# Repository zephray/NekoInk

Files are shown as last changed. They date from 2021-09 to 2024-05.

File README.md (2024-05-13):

NekoInk
=======

**This project has been superseded by [Glider](https://gitlab.com/zephray/glider) and will not be updated further.**

NekoInk is an open-source, programmable, and versatile E-paper display platform. It offers connectivity options to various type of E-paper screens, and flexible programming environment choices.

# Hardware

## Mainboard

The 1st generation of NekoInk has the following specs:

* Processing
    - NXP i.MX6ULL, 900 MHz Cortex-A7 processor
    - 512 MB DDR3L-1066 memory
* Display
    - Support for EPD screens from 6" to 13.3"
    - Up to 32 greyscale levels / 32768 colors (depends on screen)
    - 40 pin connector for ED103TC1/ES103TC2/GDEW101C01
    - 6 and 12 pin connector for capacitive touch screen (shared signal)
    - 30 pin connector for LVDS LCDs
* Connectivity
    - MicroSD slot for storage
    - 1x USB Micro-B for USB Device and charging
    - 1x USB Micro-AB for USB Host
    - 1x USB Micro-B for USB Serial terminal
    - 1x DVP port for HDMI input or camera module
    - Integrated WiFi and Bluetooth
* Power
    - AXP209 PMIC with Lithium battery charger and coulomb counter
    - Power consumption T.B.D.

## Screen Adapter

Adapter boards are available in this repo to adapt the following screens:

* 39 pin connector for ED060SC4/ED133UT2
* 34 pin connector for ED060SCF/SCN/SCP/XC3/XC5/XC9/XD4/XD6/XH2/KC1/KD1
* 35 pin connector for ED060XC8/TC1
* 50 pin connector for ES108FC1

It's possible to use a simple FPC extender to support the following screens:

* ED078KC1/KH4/GDEW078M01/078C01

The hardware is designed with KiCAD 7.0.

## Status

The 1st gen mainboard is finished, soldered, and tested and considered stable. However there is no plan for mass-production.

# Software

T.B.D.

## Operating System

Linux T.B.D.

## Waveform

This project uses a human-readable waveform format (iwf, Interchangable Waveform Format) described below. Currently this could be converted into .fw format used by i.MX6/7 EPDC/EPDCv2. Converting from Eink's wbf format is also supported.

### Waveform Format

The waveform consists of one descriptor file in iwf extension (ini format) and various lut data files in csv format.

The descriptor contains the follwoing required fields:

* VERISON: the version of the descriptor
* NAME: (optional) original name for the waveform
* BPP: (optional, default 4) 4 or 5, representing the internal state count used for waveform
* PREFIX: the filename prefix for actual waveform files
* MODES: the total modes supported by the waveform
* TEMPS: the total number of temperature ranges supported by the waveform
* T*x*RANGE: the supported temperature in degC, where x is the temperature ID
* TUPBOUND: (optional) upper bound for temperature range, each range is T*x*RANGE to T*x+1*RANGE (or TUPBOUND in case of the last one)

In v2.0, the following fields are added:

* TABLES: total number of LUTs inside the waveform
* TB*x*FC: the frame count for the table, where x is the table ID

In v1.0, table are directly addressed and stored by its mode and temperature ID (expect things like PREFIX_M1_T2.csv for mode 1 and temperature range 2). In v2.0, tables are indirectly addressed and stored (expect things like PREFIX_TB2.csv for the second table, and one or more mode/temperature combination to use/ reference table 2).

Each mode has its own mode section named \[MODE*x*\], where x is the mode ID, containing the following fields:

* NAME: the name for that mode
* TxFC: the frame count for the temperature in that mode, where x is the temperature ID (v1.0 only)
* T*TABLE: the table used for the temperature in that mode (v2.0 only)

There should be a number of LUTs, saved in the filename of either PREFIX_M*x*_T*y*.csv (v1.0) or PREFIX_TB*x*.csv. Each csv file should contain the a LUT like this: lut\[src\]\[dst\]\[frame\], which means, to transition from src greyscale level to dst greyscale level, at a certain frame in a frame sequence, what voltage should be applied to the screen (0/3: GND / Keep, 1: VNEG / To black, 2: VPOS / To white). Each line contains the frame sequence for one or more source to destination pairs.

For example:

* ```4,7,1,1,1,0,2``` means to transition from greyscale level 4 to greyscale level 7, there should be 5 frames, each applying VNEG VNEG VNEG GND VPOS
* ```0:14:15,2,2,2``` means to transition from any greyscale level from 0 to 14 to greyscale level 15, there should be 3 frames, each applying VPOS VPOS VPOS

These are provided to only illustrate the file format, they are not valid or meaningful Eink driving sequences.

With current design, each mode should have fixed frame count for all associated frame sequences.

### Converting

Tools are provided in utils/ folder.

* To convert from iwf to fw (iMX6/7 EPDC format): ```./mxc_wvfm_asm v1/v2 input.iwf output.fw``` 
* To convert from fw to iwf: ```./mxc_wvfm_dump v1/v2 input.fw output_prefix```
* To convert from wbf to iwf: ```./wbf_wvfm_dump input.wbf output_prefix```

In some cases, the waveform stored on the panel/ controller's flash is compressed. A decompressing tool is also provided that might work.

### Generating

To be implemented.

# License

The design, unless otherwise specified, is released under the CERN Open Source Hardware License version 2 permissive variant, CERN-OHL-P. A copy of the license is provided in the source repository. Additionally, user guide of the license is provided on ohwr.org.

The waveform converting tool is licensed under GNU GPLv2+ due to use of Linux kernel source code and other people's valuable prior work. See each tools' source code for the complete copyright.

The image viewer tool is licensed under MIT. stb library used in the image viewer is public domain.

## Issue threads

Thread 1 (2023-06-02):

ES108FC1

vdp, 2023-06-02:
May I ask on which reference is the pinout used for the ES108FC1 adapter based?

I see that there is for example GDSP signal on pin 43, which is not there in [the datasheet I've found](https://github.com/vroland/epdiy/files/10342125/ES108FC1_Ver0.1.pdf). I'm having trouble driving this screen- it just behaves strangely... For example it only updates at some random instant, then nothing happens, then it may or may not update some time later and so on... Having something left floating which shouldn't be would explain this erratic behaviour, I think. The above preliminary spec is the only 'official' document I've been able to find. This panel is used in Lenovo Yoga Book C930, but the only way to get a schematic seem to be through shady sites which ask to pay them. I would have considered it, but I'm not sure the doc they offer contains relevant info in the first place.

Thanks for your time!

zephray, 2023-06-12:
Hi sorry forgot to reply last week.

It's mainly based on the datasheet you found. However I encountered the same issue as you did, the screen just doesn't work. From looking at the screen flex cable it's obvious these pins are certainly not NC. Basically from trial and error I noticed that connecting GDSP to pin 43 allowed it to work. This is later confirmed by looking at the schematics of C930 (one of my friend eventually decided to pull the trigger and purchased the schematics on one of those shady sites).

vdp, 2023-06-13:
Thank you very much! This is __very__ helpful, because this screen is really driving me crazy. I see that there is a jumper for SDCE0 on pin 36- is it also required for the screen to work properly?

I will try to modify my adapter to see if I can make it work. Other than these 1 or 2 changes, is there something else that I should watch for? For example I have a 10K pull-up R on the test pin 31, just as in your schematic. But I've noticed that sporadically all the lines are activated/charged at the same time, which is basically what pulsing the XON low does, as far as I can see from some driver chip datasheets I found online, so I wonder if a stronger(i.e. lower R value) pull-up may be needed... Also is there anything peculiar about the signal timing for example, that is different from how the other screens are typically driven?

vdp, 2023-06-13:
Thanks a lot! This info is really valuable. Hopefully I will be able to make it work now. (closing the ticket)

Closed 2023-06-13.

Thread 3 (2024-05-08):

v2 MXC Assembly not supported

stephendpmurphy, 2024-05-08:
Hello, I'm attempting to run a conversion from a .WBF to a .FW that the v2 EPDC driver can handle. The conversion from .wbf to .iwf appears to run correctly but it looks like the MXC assembly bin is intentionally asserting that the version of the input file must be for the MXC v1 driver. Is this correct? I'm guessing the assembly piece just isn't finished for the v2 EPDC driver file format?

zephray, 2024-05-09:
The issue is actually that I wrote the WBF decoder much later than the FW decoder/ assembler. So by the time I wrote the WBF decoder I found the initial IWF format I defined is inadequate, so I created a IWF v2 format (likely no one other than me is using the IWF V1 format anyway). But then I never got around to update the FW decoder/ assembler to properly support IWF v2. Thanks for the reminder and I will do that soon. Though if you are trying to use WBF on NXP devices, I would also recommend just reach out to NXP FAEs, they have their proprietary tool for doing so.

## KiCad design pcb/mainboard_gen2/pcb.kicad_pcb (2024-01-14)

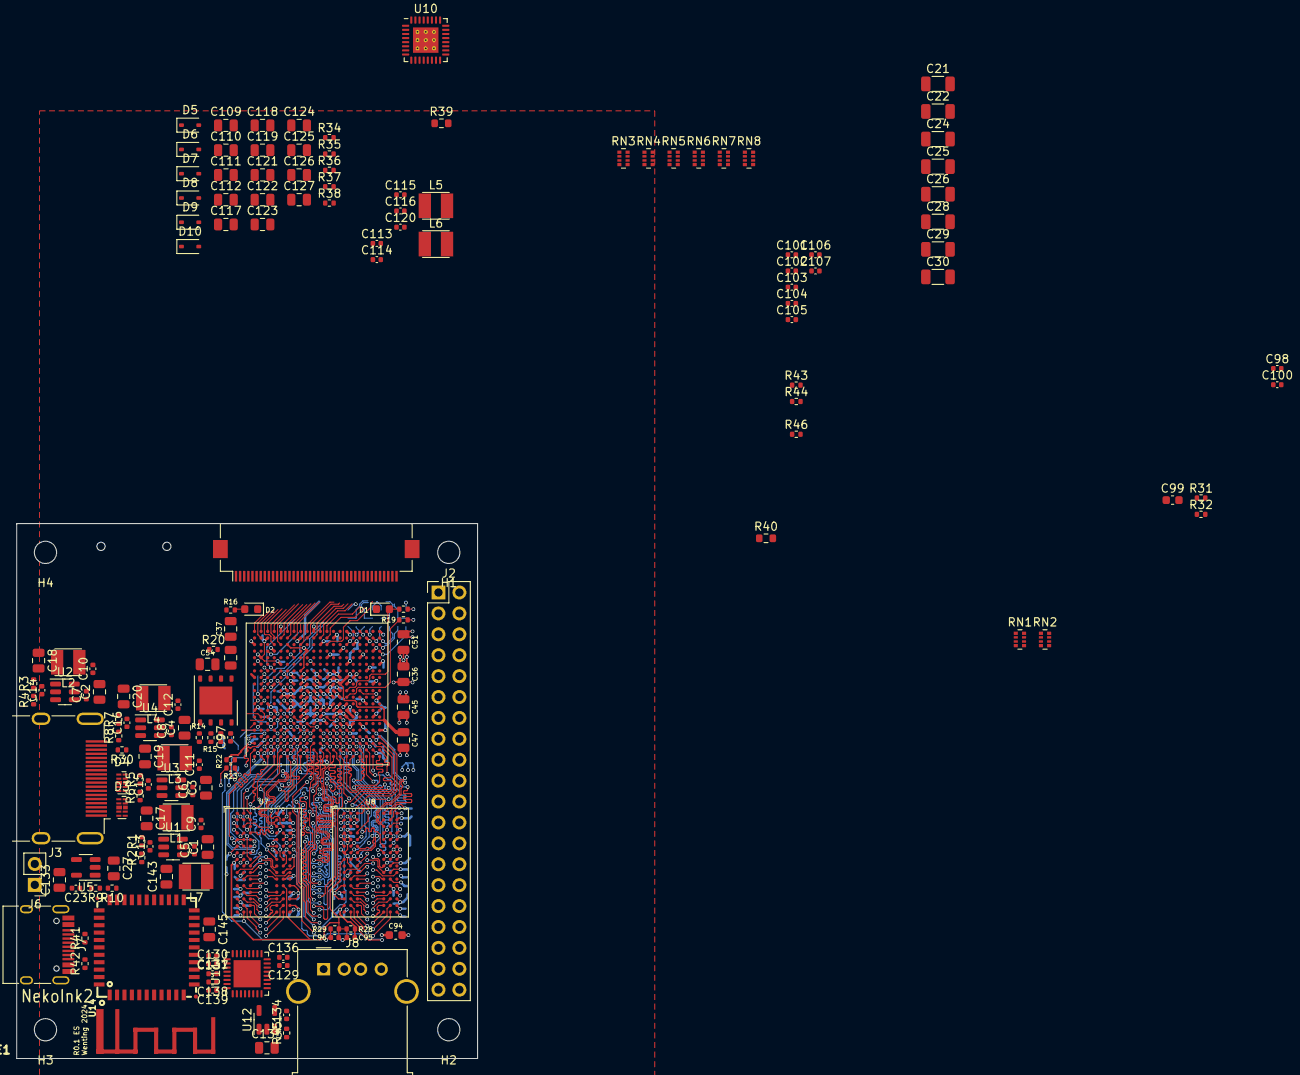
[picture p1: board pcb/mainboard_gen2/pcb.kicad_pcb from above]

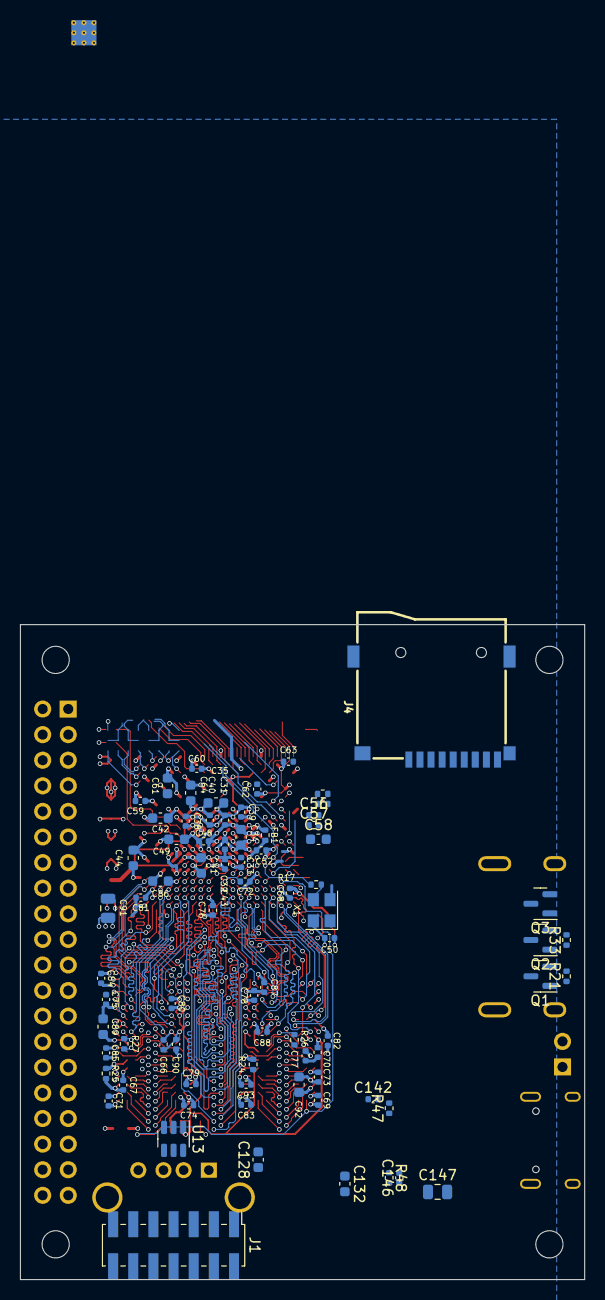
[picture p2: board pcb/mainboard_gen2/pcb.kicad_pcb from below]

Board: 6 copper layers, 56.0 x 65.0 mm, 245 parts (77 on the bottom side), 245 nets.

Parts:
AE1: Antenna_Shield; bt_antenna_1ant_2gnd_mirror
C1, C2, C3, C4, C17, C18, C19, C20, C27, C119, C125, C133, C135, C143, C145, C147: 10uF; C_0805_2012Metric
C5, C6, C7, C8, C9, C10, C11, C12, C23, C67, C70, C95, C96, C100, C113, C114, C115, C129, C130, C131, C134, C136, C137, C138, C139, C142, C146: 100nF; C_0402_1005Metric
C13, C14, C15, C16: 47pF; C_0402_1005Metric
C21, C22, C24, C25, C26, C28, C29, C30: 47uF/10V; C_1206_3216Metric
C31, C32, C33, C38, C39, C40, C43, C48, C50, C52, C56, C57, C59, C60, C62, C63, C68, C72, C76, C81, C97: 470nF; C_0402_1005Metric
C34, C35, C41, C42, C44, C49, C58, C61, C64, C86, C94, C128, C132: 4.7uF; C_0603_1608Metric
C36, C37, C45, C46, C47, C51: 100uF; C_0805_2012Metric
C54, C91: 47uF; C_0805_2012Metric
C66, C69, C71, C73, C74, C75, C77, C78, C79, C80, C82, C83, C84, C85, C87, C88, C90, C93, C101, C102, C103, C104, C105, C106, C107: 220nF; C_0402_1005Metric
C89, C92, C99: 22uF; C_0603_1608Metric
C98: 18pF; C_0402_1005Metric
C109, C110, C111, C112: 1uF/25V; C_0805_2012Metric
C116: 1uF; C_0402_1005Metric
C117, C118, C121, C122, C123, C124, C126, C127: 4.7uF/25V; C_0805_2012Metric
C120: 2.2nF; C_0402_1005Metric
D1, D2: LED; LED_0603_1608Metric
D3, D4: RCLAMP0524P; Diodes_UDFN-10_1.0x2.5mm_P0.5mm
D5, D6, D7, D8, D9, D10: B0530WS; D_SOD-323
FB1: 120R; R_0402_1005Metric
H1, H2, H3, H4: MountingHole; MountingHole_2.7mm_M2.5
J1: JTAG; PinHeader_2x07_P2.00mm_Vertical_SMD
J2: GPIO; PinHeader_2x20_P2.54mm_Vertical
J3: HDMI_A; HDMI_A_Molex_208658-1001_Horizontal
J4: MICRO_SD(TFC-WPAPR-08); TFC-WPAPR-08
J5: 0.5mm; Hirose_FH12-40S-0.5SH_1x40-1MP_P0.50mm_Horizontal_Reversed
J6: Conn_01x02; PinHeader_1x02_P2.54mm_Vertical
J7: USB_C_Receptacle_USB2.0; USB_C_Receptacle_HRO_TYPE-C-31-M-12
J8: USB_A; USB_A_Molex_67643_Horizontal
L1, L2, L3, L4, L5, L6, L7: 4.7uH; L_1212
Q1, Q2, Q3: BSS138; SOT-23
R1: 91K/1%; R_0402_1005Metric
R2, R3, R5: 20K/1%; R_0402_1005Metric
R4: 10K/1%; R_0402_1005Metric
R6, R7: 16K/1%; R_0402_1005Metric
R8, R36: 27K/1%; R_0402_1005Metric
R9, R19: 4.7K; R_0402_1005Metric
R10: 16K; R_0402_1005Metric
R11, R12, R13, R14, R15, R31: 20K; R_0402_1005Metric
R16, R18, R30, R46: 1K; R_0402_1005Metric
R17, R32, R43, R47, R48: 22R; R_0402_1005Metric
R20, R21, R33, R41, R42, R45: 10K; R_0402_1005Metric
R22, R23: 80R; R_0402_1005Metric
R24, R25: 240R 1%; R_0402_1005Metric
R26, R27: 100R; R_0402_1005Metric
R28, R29: 1.5K/0.5%; R_0402_1005Metric
R34: 562K/1%; R_0402_1005Metric
R35: 806K/1%; R_0402_1005Metric
R37: 49.9K/1%; R_0402_1005Metric
R38: 10R; R_0402_1005Metric
R39: 0.5R; R_0603_1608Metric
R40: 22R; R_0603_1608Metric
R44: 12K/1%; R_0402_1005Metric
RN1, RN2: 51; R_Array_Convex_4x0402
RN3, RN4, RN5, RN6, RN7, RN8: 33; R_Array_Convex_4x0402
U1, U2, U3, U4: SY8120; TSOT-23-6
U5, U12: MT9700; SOT-23-5
U6: XC7Z010-CLG400; Xilinx_CLG400
U7, U8: MT41K256M16HA; BGA-96_9.0x13.0mm_Layout2x3x16_P0.8mm
U9: W25Q128JVP; WSON-8-1EP_6x5mm_P1.27mm_EP3.4x4mm
U10: MAX17135; QFN-32-1EP_5x5mm_P0.5mm_EP3.1x3.1mm_ThermalVias
U11: USB3300; QFN-32-1EP_5x5mm_P0.5mm_EP3.3x3.3mm
U13: USBLC6-2SC6; SOT-23-6
U14: AP6330(BCM4330); RL-SM02BD(RTL8723BS)
X1: 33.33MHz; Oscillator_SMD_Abracon_ASE-4Pin_3.2x2.5mm

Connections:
+1V0: C16.2, C20.2, C31.1, C33.1, C35.1, C37.1, C38.1, C39.1, C40.1, C41.1, C42.1, C46.1, C47.1, L4.2, R7.2, U6.G7 (VCCPINT[6]), U6.G11 (VCCBRAM[2]), U6.G13 (VCCINT[9]), U6.H10 (VCCBRAM[2]), U6.H12 (VCCINT[9]), U6.J7 (VCCPINT[6]), U6.J13 (VCCINT[9]), U6.K12 (VCCINT[9]), U6.L7 (VCCPINT[6]), U6.L13 (VCCINT[9]), U6.M12 (VCCINT[9]), U6.N7 (VCCPINT[6]), U6.N13 (VCCINT[9]), U6.P8 (VCCPINT[6]), U6.P12 (VCCINT[9]), U6.R7 (VCCPINT[6]), U6.R13 (VCCINT[9])
+1V8: C14.2, C18.2, C32.1, C34.1, C36.1, C48.1, C49.1, C51.1, C59.1, C60.1, C61.1, FB1.2, L2.2, R3.2, U6.F8 (VCCPAUX[5]), U6.F11 (VCCBATT_0), U6.G9 (VCCPAUX[5]), U6.H8 (VCCPAUX[5]), U6.J9 (VCCADC_0), U6.J11 (VCCAUX[6]), U6.K8 (VCCPAUX[5]), U6.L11 (VCCAUX[6]), U6.M8 (VCCPAUX[5]), U6.N9 (VCCAUX[6]), U6.N11 (VCCAUX[6]), U6.N19 (VCCO_34[6]), U6.P10 (VCCAUX[6]), U6.R9 (VCCAUX[6]), U6.R15 (VCCO_34[6]), U6.T18 (VCCO_34[6]), U6.V14 (VCCO_34[6]), U6.W17 (VCCO_34[6]), U6.Y20 (VCCO_34[6])
+1V35: C15.2, C19.2, C66.1, C68.1, C69.1, C71.1, C72.1, C73.1, C74.1, C75.1, C76.1, C77.1, C78.1, C79.1, C80.1, C81.1, C82.1, C83.1, C84.1, C85.1, C86.1, C87.1, C88.1, C89.1, C90.1, C91.1, C92.1, C93.1, C94.1, C95.1, L3.2, R5.2, R22.1, R28.1, U6.A3 (VCCO_DDR_502[10]), U6.D2 (VCCO_DDR_502[10]), U6.E5 (VCCO_DDR_502[10]), U6.G1 (VCCO_DDR_502[10]), U6.H4 (VCCO_DDR_502[10]), U6.L3 (VCCO_DDR_502[10]), U6.P2 (VCCO_DDR_502[10]), U6.R5 (VCCO_DDR_502[10]), U6.U1 (VCCO_DDR_502[10]), U6.V4 (VCCO_DDR_502[10]), U7.A1 (VDDQ), U7.A8 (VDDQ), U7.B2 (VDD), U7.C1 (VDDQ), U7.C9 (VDDQ), U7.D2 (VDDQ), U7.D9 (VDD), U7.E9 (VDDQ), U7.F1 (VDDQ), U7.G7 (VDD), U7.H2 (VDDQ), U7.H9 (VDDQ), U7.K2 (VDD), U7.K8 (VDD), U7.N1 (VDD), U7.N9 (VDD), U7.R1 (VDD), U7.R9 (VDD), U8.A1 (VDDQ), U8.A8 (VDDQ), U8.B2 (VDD), U8.C1 (VDDQ), U8.C9 (VDDQ), U8.D2 (VDDQ), U8.D9 (VDD), U8.E9 (VDDQ), U8.F1 (VDDQ), U8.G7 (VDD), U8.H2 (VDDQ), U8.H9 (VDDQ), U8.K2 (VDD), U8.K8 (VDD), U8.N1 (VDD), U8.N9 (VDD), U8.R1 (VDD), U8.R9 (VDD)
+3V3: C13.2, C17.2, C43.2, C44.2, C45.2, C50.2, C56.1, C57.1, C58.1, C62.1, C63.1, C64.1, C97.2, C99.1, C100.1, C105.1, C136.1, C137.1, C138.1, C139.1, C142.1, C145.1, C146.1, C147.1, J1.2, J2.1, J2.17, J4.4 (VDD), J5.5, J5.11, L1.2, Q1.1 (G), Q2.1 (G), Q3.1 (G), R1.2, R11.1, R14.1, R18.1, R19.1, R20.1, R21.1, R31.1, R33.1, RN1.1 (R1.1), RN1.2 (R2.1), RN1.3 (R3.1), RN1.4 (R4.1), RN2.1 (R1.1), RN2.2 (R2.1), RN2.3 (R3.1), RN2.4 (R4.1), U6.A13 (VCCO_MIO1_501[4]), U6.B6 (VCCO_MIO0_500[2]), U6.B16 (VCCO_MIO1_501[4]), U6.C19 (VCCO_35[6]), U6.D7 (VCCO_MIO0_500[2]), U6.D12 (VCCO_MIO1_501[4]), U6.E15 (VCCO_MIO1_501[4]), U6.F18 (VCCO_35[6]), U6.H14 (VCCO_35[6]), U6.J17 (VCCO_35[6]), U6.K6 (VCCO_0), U6.K20 (VCCO_35[6]), U6.M6 (CFGBVS_0), U6.M16 (VCCO_35[6]), U6.N6 (RSVDVCC3), U6.R6 (RSVDVCC2), U6.T6 (RSVDVCC1), U6.T8 (VCCO_13[4]), U6.U11 (VCCO_13[4]), U6.W7 (VCCO_13[4]), U6.Y10 (VCCO_13[4]), U9.8 (VCC), U10.11 (VDD), U11.6 (VDD3.3), U11.16 (VDD3.3), U11.25 (VDD3.3), U11.30 (VDD3.3), U11.31 (REG_EN), U14.6 (BT_WAKE), U14.9 (VBAT), U14.22 (VDD_IO), X1.1 (EN), X1.4 (Vdd)
+5V: C1.2, C2.2, C3.2, C4.2, C5.2, C6.2, C7.2, C8.2, C21.2, C22.2, C24.2, C25.2, C26.2, C27.2, C28.2, C29.2, C30.2, J2.2, J2.4, R30.1, U1.4 (~SHDN), U1.5 (IN), U2.4 (~SHDN), U2.5 (IN), U3.4 (~SHDN), U3.5 (IN), U4.4 (~SHDN), U4.5 (IN), U5.1 (VOUT)
+DRAM_VREF: C67.1, C70.1, C95.2, C96.1, R28.2, R29.1, U6.H6 (PS_DDR_VREF0_502), U6.P6 (PS_DDR_VREF1_502), U7.H1 (VrefDQ), U7.M8 (VrefCA), U8.H1 (VrefDQ), U8.M8 (VrefCA)
/connector/HPD_5V: J3.19 (HPD), Q3.3 (D), R30.2
/connector/SCL_5V: J3.15 (SCL), Q1.3 (D)
/connector/SDA_5V: J3.16 (SDA), Q2.3 (D)
/cpu/FPGA_INIT_B: R19.2, U6.R10 (INIT_B_0)
/cpu/LED: R16.1, U6.E6 (PS_MIO0_500)
/cpu/PS_CLK: R17.2, U6.E7 (PS_CLK_500)
/cpu/VCCPLL: C52.2, C54.2, FB1.1, U6.G8 (VCCPLL)
/ddr/DRAM_ADDR0: U6.N2 (PS_DDR_A0_502), U7.N3 (A0), U8.N3 (A0)
/ddr/DRAM_ADDR1: U6.K2 (PS_DDR_A1_502), U7.P7 (A1), U8.P7 (A1)
/ddr/DRAM_ADDR2: U6.M3 (PS_DDR_A2_502), U7.P3 (A2), U8.P3 (A2)
/ddr/DRAM_ADDR3: U6.K3 (PS_DDR_A3_502), U7.N2 (A3), U8.N2 (A3)
/ddr/DRAM_ADDR4: U6.M4 (PS_DDR_A4_502), U7.P8 (A4), U8.P8 (A4)
/ddr/DRAM_ADDR5: U6.L1 (PS_DDR_A5_502), U7.P2 (A5), U8.P2 (A5)
/ddr/DRAM_ADDR6: U6.L4 (PS_DDR_A6_502), U7.R8 (A6), U8.R8 (A6)
/ddr/DRAM_ADDR7: U6.K4 (PS_DDR_A7_502), U7.R2 (A7), U8.R2 (A7)
/ddr/DRAM_ADDR8: U6.K1 (PS_DDR_A8_502), U7.T8 (A8), U8.T8 (A8)
/ddr/DRAM_ADDR9: U6.J4 (PS_DDR_A9_502), U7.R3 (A9), U8.R3 (A9)
/ddr/DRAM_ADDR10: U6.F5 (PS_DDR_A10_502), U7.L7 (A10), U8.L7 (A10)
/ddr/DRAM_ADDR11: U6.G4 (PS_DDR_A11_502), U7.R7 (A11), U8.R7 (A11)
/ddr/DRAM_ADDR12: U6.E4 (PS_DDR_A12_502), U7.N7 (A12/~BC), U8.N7 (A12/~BC)
/ddr/DRAM_ADDR13: U6.D4 (PS_DDR_A13_502), U7.T3 (A13), U8.T3 (A13)
/ddr/DRAM_ADDR14: U6.F4 (PS_DDR_A14_502), U7.T7 (A14/NC), U8.T7 (A14/NC)
/ddr/DRAM_BA0: U6.L5 (PS_DDR_BA0_502), U7.M2 (BA0), U8.M2 (BA0)
/ddr/DRAM_BA1: U6.R4 (PS_DDR_BA1_502), U7.N8 (BA1), U8.N8 (BA1)
/ddr/DRAM_BA2: U6.J5 (PS_DDR_BA2_502), U7.M3 (BA2), U8.M3 (BA2)
/ddr/DRAM_CASB: U6.P5 (PS_DDR_CAS_B_502), U7.K3 (~CAS), U8.K3 (~CAS)
/ddr/DRAM_CKE: U6.N3 (PS_DDR_CKE_502), U7.K9 (CKE), U8.K9 (CKE)
/ddr/DRAM_CKN: R26.2, R27.2, U6.M2 (PS_DDR_CKN_502), U7.K7 (~CK), U8.K7 (~CK)
/ddr/DRAM_CKP: R26.1, R27.1, U6.L2 (PS_DDR_CKP_502), U7.J7 (CK), U8.J7 (CK)
/ddr/DRAM_CSB: U6.N1 (PS_DDR_CS_B_502), U7.L2 (~CS), U8.L2 (~CS)
/ddr/DRAM_DATA0: U6.C3 (PS_DDR_DQ0_502), U7.E3 (DQ0)
/ddr/DRAM_DATA1: U6.B3 (PS_DDR_DQ1_502), U7.F7 (DQ1)
/ddr/DRAM_DATA2: U6.A2 (PS_DDR_DQ2_502), U7.F2 (DQ2)
/ddr/DRAM_DATA3: U6.A4 (PS_DDR_DQ3_502), U7.F8 (DQ3)
/ddr/DRAM_DATA4: U6.D3 (PS_DDR_DQ4_502), U7.H3 (DQ4)
/ddr/DRAM_DATA5: U6.D1 (PS_DDR_DQ5_502), U7.H8 (DQ5)
/ddr/DRAM_DATA6: U6.C1 (PS_DDR_DQ6_502), U7.G2 (DQ6)
/ddr/DRAM_DATA7: U6.E1 (PS_DDR_DQ7_502), U7.H7 (DQ7)
/ddr/DRAM_DATA8: U6.E2 (PS_DDR_DQ8_502), U7.D7 (DQ8)
/ddr/DRAM_DATA9: U6.E3 (PS_DDR_DQ9_502), U7.C3 (DQ9)
/ddr/DRAM_DATA10: U6.G3 (PS_DDR_DQ10_502), U7.C8 (DQ10)
/ddr/DRAM_DATA11: U6.H3 (PS_DDR_DQ11_502), U7.C2 (DQ11)
/ddr/DRAM_DATA12: U6.J3 (PS_DDR_DQ12_502), U7.A7 (DQ12)
/ddr/DRAM_DATA13: U6.H2 (PS_DDR_DQ13_502), U7.A2 (DQ13)
/ddr/DRAM_DATA14: U6.H1 (PS_DDR_DQ14_502), U7.B8 (DQ14)
/ddr/DRAM_DATA15: U6.J1 (PS_DDR_DQ15_502), U7.A3 (DQ15)
/ddr/DRAM_DATA16: U6.P1 (PS_DDR_DQ16_502), U8.E3 (DQ0)
/ddr/DRAM_DATA17: U6.P3 (PS_DDR_DQ17_502), U8.F7 (DQ1)
/ddr/DRAM_DATA18: U6.R3 (PS_DDR_DQ18_502), U8.F2 (DQ2)
/ddr/DRAM_DATA19: U6.R1 (PS_DDR_DQ19_502), U8.F8 (DQ3)
/ddr/DRAM_DATA20: U6.T4 (PS_DDR_DQ20_502), U8.H3 (DQ4)
/ddr/DRAM_DATA21: U6.U4 (PS_DDR_DQ21_502), U8.H8 (DQ5)
/ddr/DRAM_DATA22: U6.U2 (PS_DDR_DQ22_502), U8.G2 (DQ6)
/ddr/DRAM_DATA23: U6.U3 (PS_DDR_DQ23_502), U8.H7 (DQ7)
/ddr/DRAM_DATA24: U6.V1 (PS_DDR_DQ24_502), U8.D7 (DQ8)
/ddr/DRAM_DATA25: U6.Y3 (PS_DDR_DQ25_502), U8.C3 (DQ9)
/ddr/DRAM_DATA26: U6.W1 (PS_DDR_DQ26_502), U8.C8 (DQ10)
/ddr/DRAM_DATA27: U6.Y4 (PS_DDR_DQ27_502), U8.C2 (DQ11)
/ddr/DRAM_DATA28: U6.Y2 (PS_DDR_DQ28_502), U8.A7 (DQ12)
/ddr/DRAM_DATA29: U6.W3 (PS_DDR_DQ29_502), U8.A2 (DQ13)
/ddr/DRAM_DATA30: U6.V2 (PS_DDR_DQ30_502), U8.B8 (DQ14)
/ddr/DRAM_DATA31: U6.V3 (PS_DDR_DQ31_502), U8.A3 (DQ15)
/ddr/DRAM_DQM0: U6.A1 (PS_DDR_DM0_502), U7.E7 (LDM)
/ddr/DRAM_DQM1: U6.F1 (PS_DDR_DM1_502), U7.D3 (UDM)
/ddr/DRAM_DQM2: U6.T1 (PS_DDR_DM2_502), U8.E7 (LDM)
/ddr/DRAM_DQM3: U6.Y1 (PS_DDR_DM3_502), U8.D3 (UDM)
/ddr/DRAM_ODT: U6.N5 (PS_DDR_ODT_502), U7.K1 (ODT), U8.K1 (ODT)
/ddr/DRAM_RASB: U6.P4 (PS_DDR_RAS_B_502), U7.J3 (~RAS), U8.J3 (~RAS)
/ddr/DRAM_RST: U6.B4 (PS_DDR_DRST_B_502), U7.T2 (~RESET), U8.T2 (~RESET)
/ddr/DRAM_SDQSN_0: U6.B2 (PS_DDR_DQS_N0_502), U7.G3 (~LDQS)
/ddr/DRAM_SDQSN_1: U6.F2 (PS_DDR_DQS_N1_502), U7.B7 (~UDQS)
/ddr/DRAM_SDQSN_2: U6.T2 (PS_DDR_DQS_N2_502), U8.G3 (~LDQS)
/ddr/DRAM_SDQSN_3: U6.W4 (PS_DDR_DQS_N3_502), U8.B7 (~UDQS)
/ddr/DRAM_SDQSP_0: U6.C2 (PS_DDR_DQS_P0_502), U7.F3 (LDQS)
/ddr/DRAM_SDQSP_1: U6.G2 (PS_DDR_DQS_P1_502), U7.C7 (UDQS)
/ddr/DRAM_SDQSP_2: U6.R2 (PS_DDR_DQS_P2_502), U8.F3 (LDQS)
/ddr/DRAM_SDQSP_3: U6.W5 (PS_DDR_DQS_P3_502), U8.C7 (UDQS)
/ddr/DRAM_WEB: U6.M5 (PS_DDR_WE_B_502), U7.L3 (~WE), U8.L3 (~WE)
/usb/HOST_VBUS: C135.1, J8.1 (VBUS), R46.1, U12.1 (VOUT), U13.5 (VBUS)
/usb/USB_DM: J8.2 (D-), U11.8 (DM), U13.1 (I/O1), U13.6 (I/O1)
/usb/USB_DP: J8.3 (D+), U11.7 (DP), U13.3 (I/O2), U13.4 (I/O2)
BT_SHUTDOWN: U6.F14 (PS_MIO21_501), U14.34 (BT_RST_N)
BT_UART_RXD: U6.B18 (PS_MIO18_501), U14.42 (UART_TXD)
BT_UART_TXD: U6.D10 (PS_MIO19_501), U14.43 (UART_RXD)
DDC_SCL: Q1.2 (S), R21.2, U6.J14 (IO_L20N_T3_AD6N_35)
DDC_SDA: Q2.2 (S), R33.2, U6.N16 (IO_L21N_T3_DQS_AD14N_35)
EPDC_D0: RN4.6 (R3.2), U6.F16 (IO_L6P_T0_35)
EPDC_D1: RN4.7 (R2.2), U6.F17 (IO_L6N_T0_VREF_35)
EPDC_D2: RN4.8 (R1.2), U6.M19 (IO_L7P_T1_AD2P_35)
EPDC_D3: RN5.5 (R4.2), U6.M20 (IO_L7N_T1_AD2N_35)
EPDC_D4: RN5.6 (R3.2), U6.M17 (IO_L8P_T1_AD10P_35)
EPDC_D5: RN5.7 (R2.2), U6.L20 (IO_L9N_T1_DQS_AD3N_35)
EPDC_D6: RN5.8 (R1.2), U6.L19 (IO_L9P_T1_DQS_AD3P_35)
EPDC_D7: RN6.5 (R4.2), U6.J19 (IO_L10N_T1_AD11N_35)
EPDC_D8: RN6.6 (R3.2), U6.K19 (IO_L10P_T1_AD11P_35)
EPDC_D9: RN6.7 (R2.2), U6.B19 (IO_L2P_T0_AD8P_35)
EPDC_D10: RN6.8 (R1.2), U6.B20 (IO_L1N_T0_AD0N_35)
EPDC_D11: RN7.5 (R4.2), U6.A20 (IO_L2N_T0_AD8N_35)
EPDC_D12: RN7.6 (R3.2), U6.E18 (IO_L5P_T0_AD9P_35)
EPDC_D13: RN7.7 (R2.2), U6.D20 (IO_L4N_T0_35)
EPDC_D14: RN7.8 (R1.2), U6.D19 (IO_L4P_T0_35)
EPDC_D15: RN8.5 (R4.2), U6.E17 (IO_L3P_T0_DQS_AD1P_35)
EPDC_GDCLK: RN3.7 (R2.2), U6.J15 (IO_25_35)
EPDC_GDOE: RN3.6 (R3.2), U6.G14 (IO_0_35)
EPDC_GDSP: RN3.8 (R1.2), U6.C20 (IO_L1P_T0_AD0P_35)
EPDC_SDCE0: RN8.6 (R3.2), U6.E19 (IO_L5N_T0_AD9N_35)
EPDC_SDCLK: RN4.5 (R4.2), U6.D18 (IO_L3N_T0_DQS_AD1N_35)
EPDC_SDLE: RN8.7 (R2.2), U6.L17 (IO_L11N_T1_SRCC_35)
EPDC_SDOE: RN8.8 (R1.2), U6.M18 (IO_L8N_T1_AD10N_35)
FPGA_DONE: D1.2 (A), Q3.2 (S), R18.2, U6.L15 (IO_L22N_T3_AD7N_35), U6.R11 (DONE_0)
FPGA_TCK: J1.6, U6.F9 (TCK_0)
FPGA_TDI: J1.10, U6.G6 (TDI_0)
FPGA_TDO: J1.8, U6.F6 (TDO_0)
FPGA_TMS: J1.4, U6.J6 (TMS_0)
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

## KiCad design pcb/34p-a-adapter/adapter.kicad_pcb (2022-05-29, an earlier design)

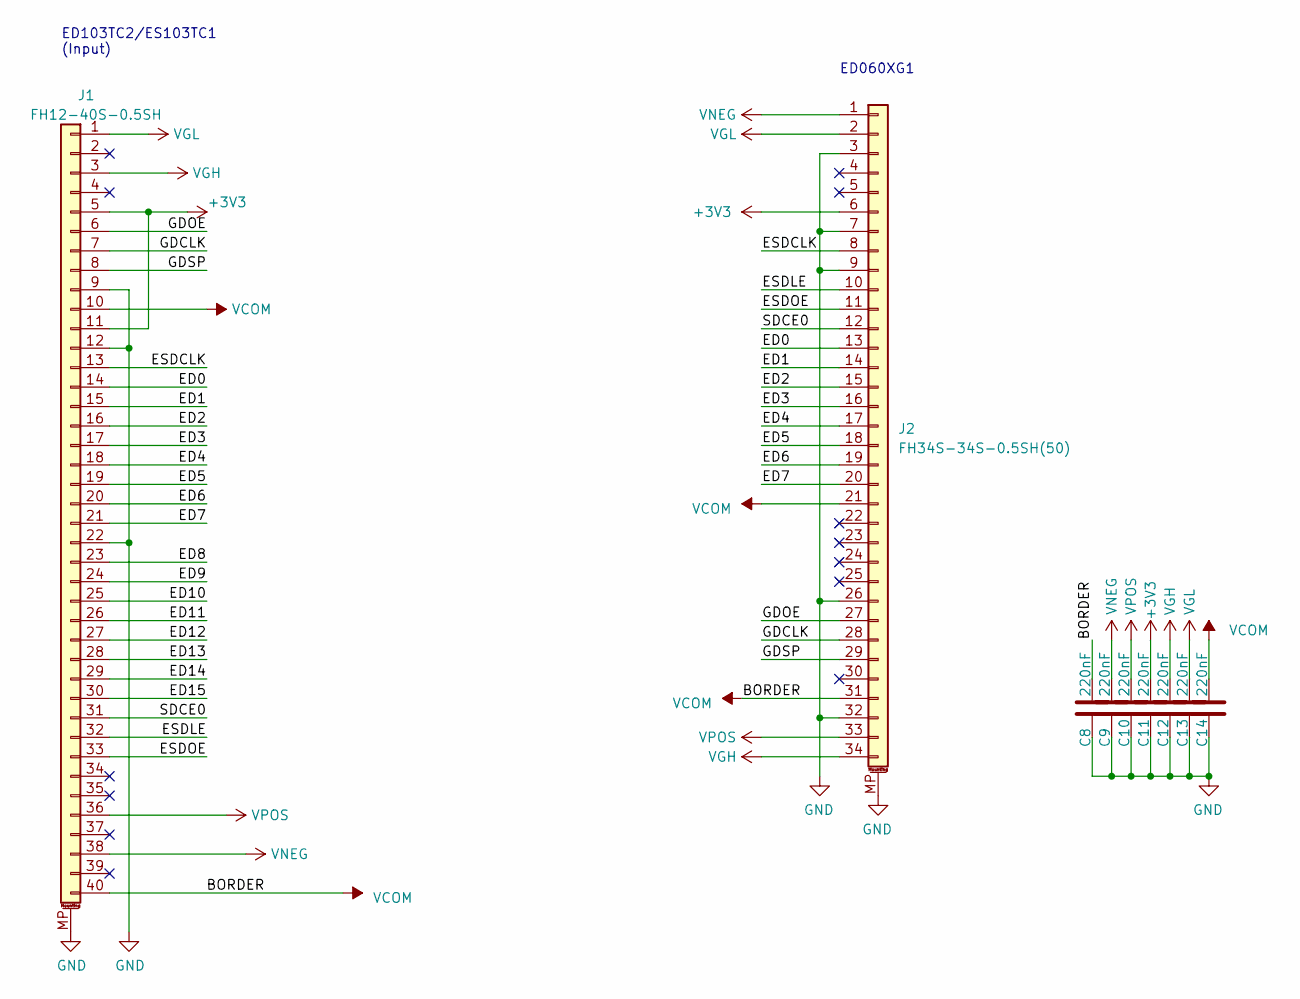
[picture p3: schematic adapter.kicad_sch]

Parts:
C8, C9, C10, C11, C12, C13, C14: 220nF; C_0402_1005Metric; LCSC C880414
J1: FH12-40S-0.5SH; Hirose_FH12-40S-0.5SH_1x40-1MP_P0.50mm_Horizontal_Reversed
J2: FH34S-34S-0.5SH(50); Hirose_FH12-34S-0.5SH_1x34-1MP_P0.50mm_Horizontal

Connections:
+3V3: C11.1, J1.5, J1.11, J2.6
/ED0: J1.14, J2.13
/ED1: J1.15, J2.14
/ED2: J1.16, J2.15
/ED3: J1.17, J2.16
/ED4: J1.18, J2.17
/ED5: J1.19, J2.18
/ED6: J1.20, J2.19
/ED7: J1.21, J2.20
/ED8: J1.23
/ED9: J1.24
/ED10: J1.25
/ED11: J1.26
/ED12: J1.27
/ED13: J1.28
/ED14: J1.29
/ED15: J1.30
/ESDCLK: J1.13, J2.8
/ESDLE: J1.32, J2.10
/ESDOE: J1.33, J2.11
/GDCLK: J1.7, J2.28
/GDOE: J1.6, J2.27
/GDSP: J1.8, J2.29
/SDCE0: J1.31, J2.12
GND: C8.2, C9.2, C10.2, C11.2, C12.2, C13.2, C14.2, J1.9, J1.12, J1.22, J1.MP (MountPin), J2.3, J2.7, J2.9, J2.26, J2.32, J2.MP (MountPin)
VCOM: C8.1, C14.1, J1.10, J1.40, J2.21, J2.31
VGH: C12.1, J1.3, J2.34
VGL: C13.1, J1.1, J2.2
VNEG: C9.1, J1.38, J2.1
VPOS: C10.1, J1.36, J2.33

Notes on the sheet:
ED103TC2/ES103TC1 (Input)
ED060XG1

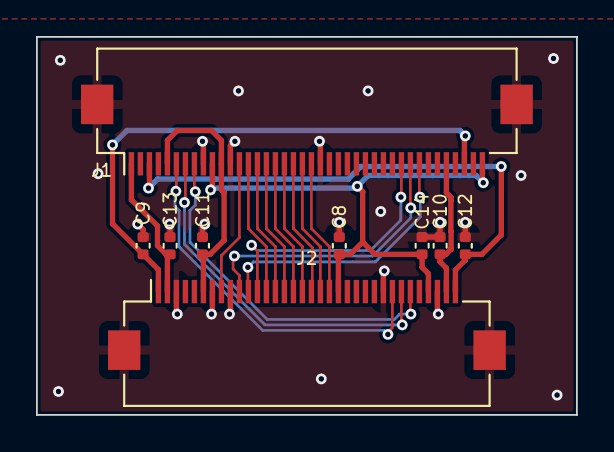
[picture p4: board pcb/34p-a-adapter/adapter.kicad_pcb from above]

Board: 2 copper layers, 30.0 x 21.0 mm, 9 parts (0 on the bottom side), 22 nets.

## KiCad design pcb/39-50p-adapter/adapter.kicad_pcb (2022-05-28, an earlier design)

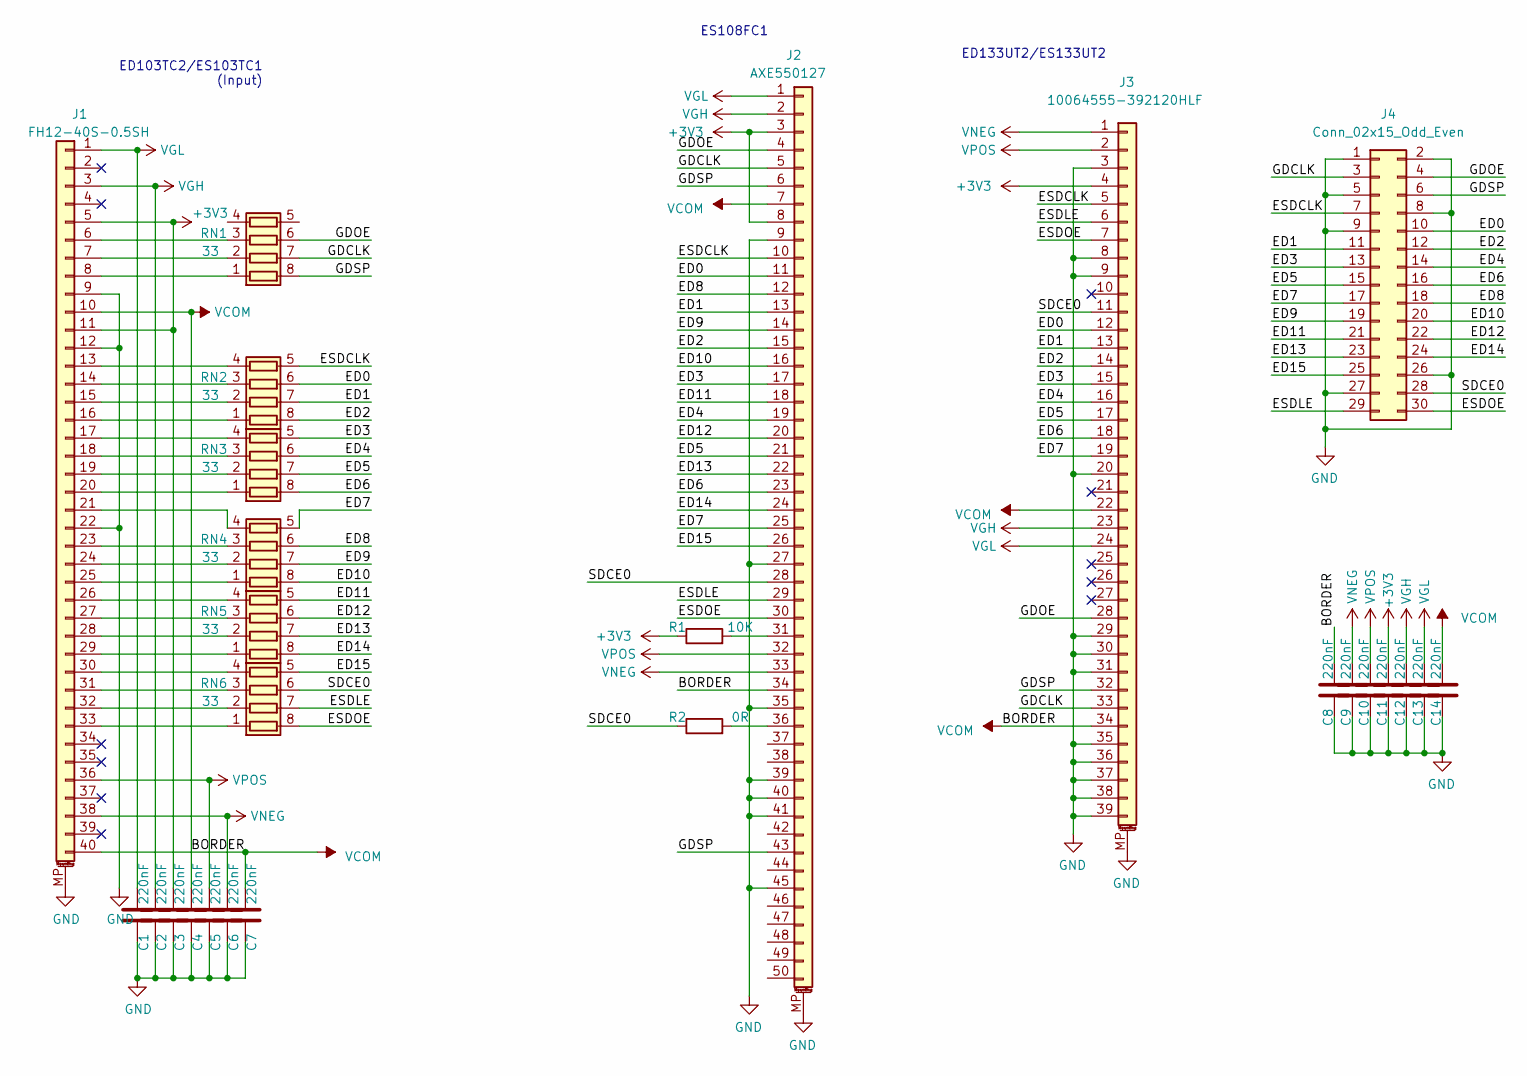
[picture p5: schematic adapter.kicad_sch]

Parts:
C1, C2, C3, C4, C5, C6, C7: 220nF; C_0402_1005Metric
C8, C9, C10, C11, C12, C13, C14: 220nF; C_0402_1005Metric; LCSC C880414
J1: FH12-40S-0.5SH; Hirose_FH12-40S-0.5SH_1x40-1MP_P0.50mm_Horizontal_Reversed
J2: AXE550127
J3: 10064555-392120HLF; FCI_10064555-392120HLF; LCSC 609-10064555-392120HLFCT-ND
J4: Conn_02x15_Odd_Even; PinHeader_2x15_P2.00mm_Vertical
R1: 10K; R_0402_1005Metric; LCSC C105870
R2: 0R; R_0402_1005Metric; LCSC C60485
RN1, RN2, RN3, RN4, RN5, RN6: 33; R_Array_Convex_4x0402

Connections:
/ED0: J2.11, J3.12, J4.10, RN2.6 (R3.2)
/ED1: J2.13, J3.13, J4.11, RN2.7 (R2.2)
/ED2: J2.15, J3.14, J4.12, RN2.8 (R1.2)
/ED3: J2.17, J3.15, J4.13, RN3.5 (R4.2)
/ED4: J2.19, J3.16, J4.14, RN3.6 (R3.2)
/ED5: J2.21, J3.17, J4.15, RN3.7 (R2.2)
/ED6: J2.23, J3.18, J4.16, RN3.8 (R1.2)
/ED7: J2.25, J3.19, J4.17, RN4.5 (R4.2)
/ED8: J2.12, J4.18, RN4.6 (R3.2)
/ED9: J2.14, J4.19, RN4.7 (R2.2)
/ED10: J2.16, J4.20, RN4.8 (R1.2)
/ED11: J2.18, J4.21, RN5.5 (R4.2)
/ED12: J2.20, J4.22, RN5.6 (R3.2)
/ED13: J2.22, J4.23, RN5.7 (R2.2)
/ED14: J2.24, J4.24, RN5.8 (R1.2)
/ED15: J2.26, J4.25, RN6.5 (R4.2)
/ESDCLK: J2.10, J3.5, J4.7, RN2.5 (R4.2)
/ESDLE: J2.29, J3.6, J4.29, RN6.7 (R2.2)
/ESDOE: J2.30, J3.7, J4.30, RN6.8 (R1.2)
/GDCLK: J2.5, J3.33, J4.3, RN1.7 (R2.2)
/GDOE: J2.4, J3.28, J4.4, RN1.6 (R3.2)
/GDSP: J2.6, J2.43, J3.32, J4.6, RN1.8 (R1.2)
/SDCE0: J2.28, J3.11, J4.28, R2.1, RN6.6 (R3.2)
GND: C1.2, C2.2, C3.2, C4.2, C5.2, C6.2, C7.2, C8.2, C9.2, C10.2, C11.2, C12.2, C13.2, C14.2, J1.9, J1.12, J1.22, J1.MP (MountPin), J2.9, J2.27, J2.35, J2.39, J2.40, J2.41, J2.45, J2.MP (MountPin), J3.3, J3.8, J3.9, J3.20, J3.29, J3.30, J3.31, J3.35, J3.36, J3.37, J3.38, J3.39, J3.MP (MountPin), J4.1, J4.2, J4.5, J4.8, J4.9, J4.26, J4.27
unnamed: J1.6, RN1.3 (R3.1)
unnamed: J1.7, RN1.2 (R2.1)
unnamed: J1.8, RN1.1 (R1.1)
unnamed: J1.13, RN2.4 (R4.1)
unnamed: J1.14, RN2.3 (R3.1)
unnamed: J1.15, RN2.2 (R2.1)
unnamed: J1.16, RN2.1 (R1.1)
unnamed: J1.17, RN3.4 (R4.1)
unnamed: J1.18, RN3.3 (R3.1)
unnamed: J1.19, RN3.2 (R2.1)
unnamed: J1.20, RN3.1 (R1.1)
unnamed: J1.21, RN4.4 (R4.1)
unnamed: J1.23, RN4.3 (R3.1)
unnamed: J1.24, RN4.2 (R2.1)
unnamed: J1.25, RN4.1 (R1.1)
unnamed: J1.26, RN5.4 (R4.1)
unnamed: J1.27, RN5.3 (R3.1)
unnamed: J1.28, RN5.2 (R2.1)
unnamed: J1.29, RN5.1 (R1.1)
unnamed: J1.30, RN6.4 (R4.1)
unnamed: J1.31, RN6.3 (R3.1)
unnamed: J1.32, RN6.2 (R2.1)
unnamed: J1.33, RN6.1 (R1.1)
unnamed: J2.31, R1.2
unnamed: J2.36, R2.2
VCOM: C4.1, C7.1, C8.1, C14.1, J1.10, J1.40, J2.7, J2.34, J3.22, J3.34
VGH: C2.1, C12.1, J1.3, J2.2, J3.23
VGL: C1.1, C13.1, J1.1, J2.1, J3.24
VNEG: C6.1, C9.1, J1.38, J2.33, J3.1
VPOS: C5.1, C10.1, J1.36, J2.32, J3.2

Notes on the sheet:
ES108FC1
ED103TC2/ES103TC1 (Input)
ED133UT2/ES133UT2

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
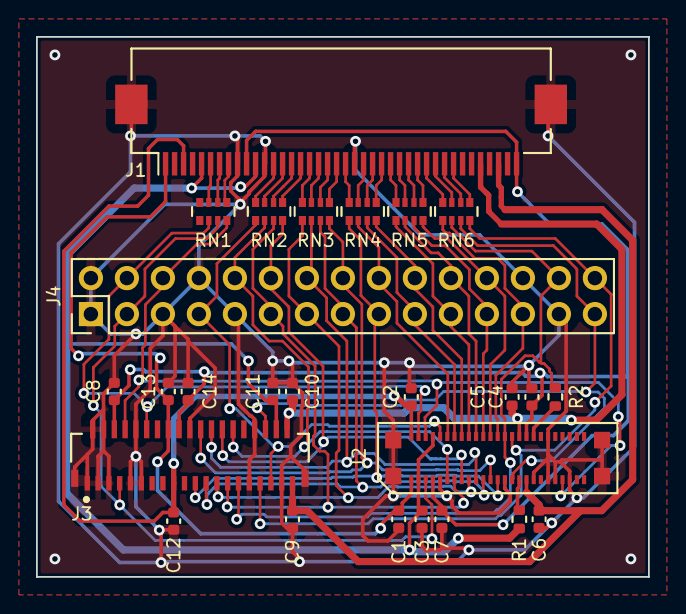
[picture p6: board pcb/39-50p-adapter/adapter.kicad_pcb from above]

Board: 2 copper layers, 34.0 x 30.0 mm, 26 parts (0 on the bottom side), 55 nets.

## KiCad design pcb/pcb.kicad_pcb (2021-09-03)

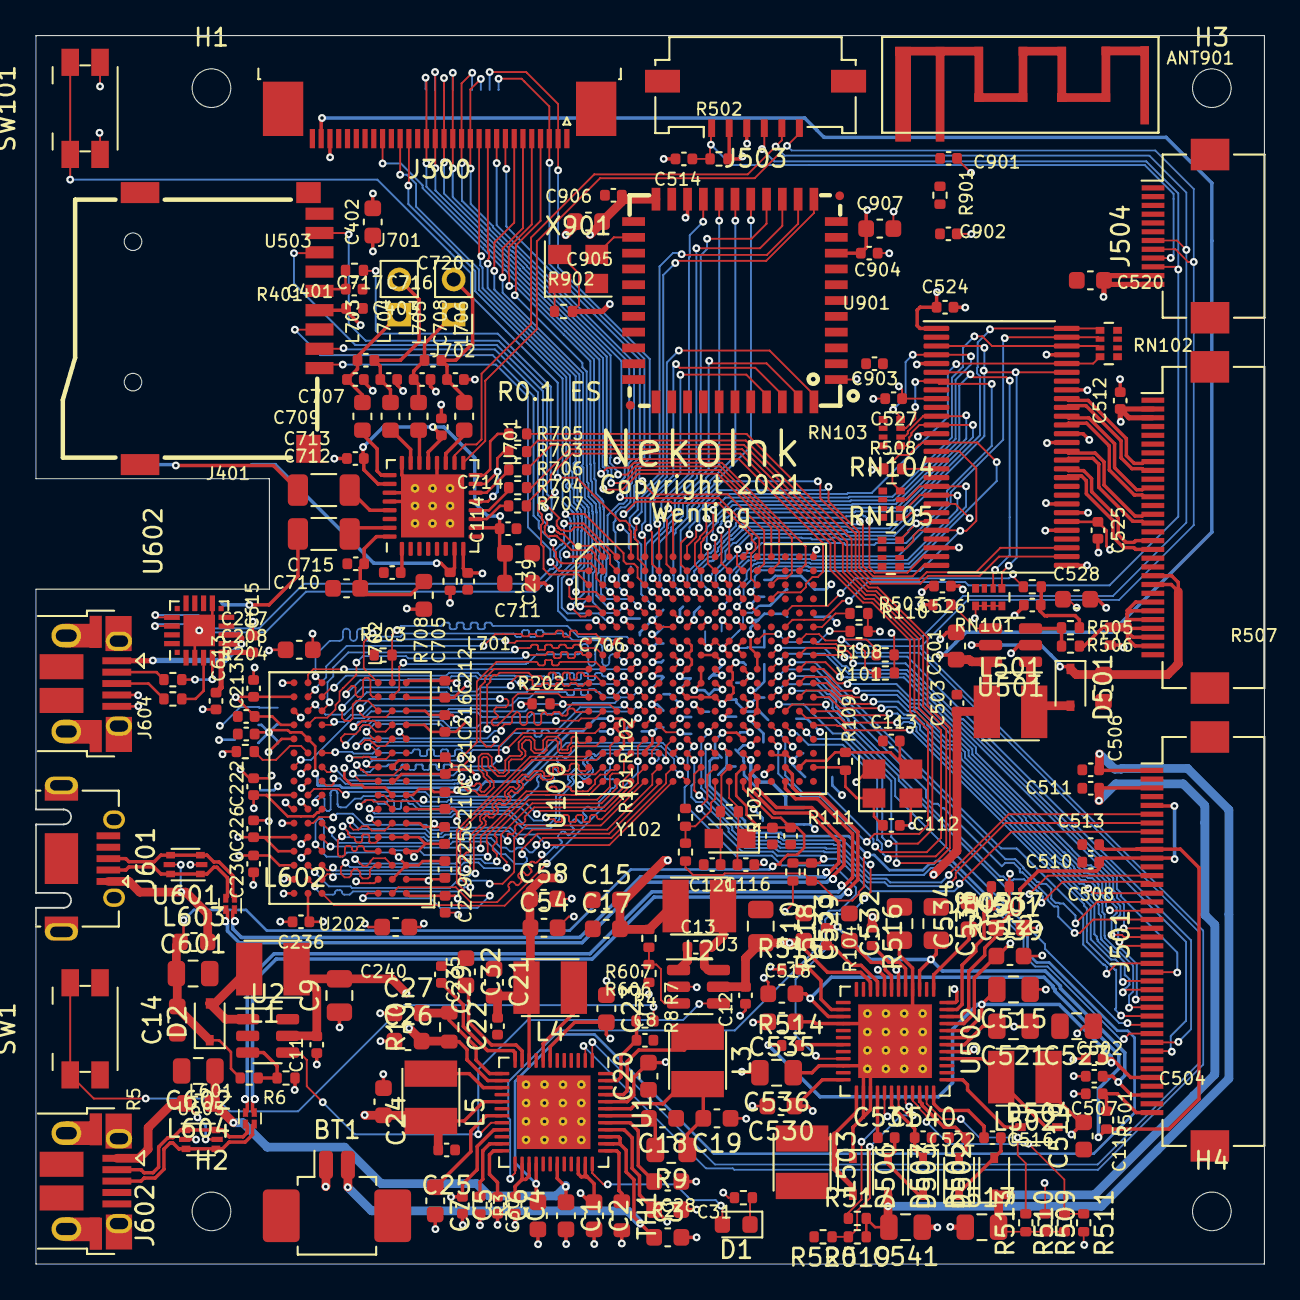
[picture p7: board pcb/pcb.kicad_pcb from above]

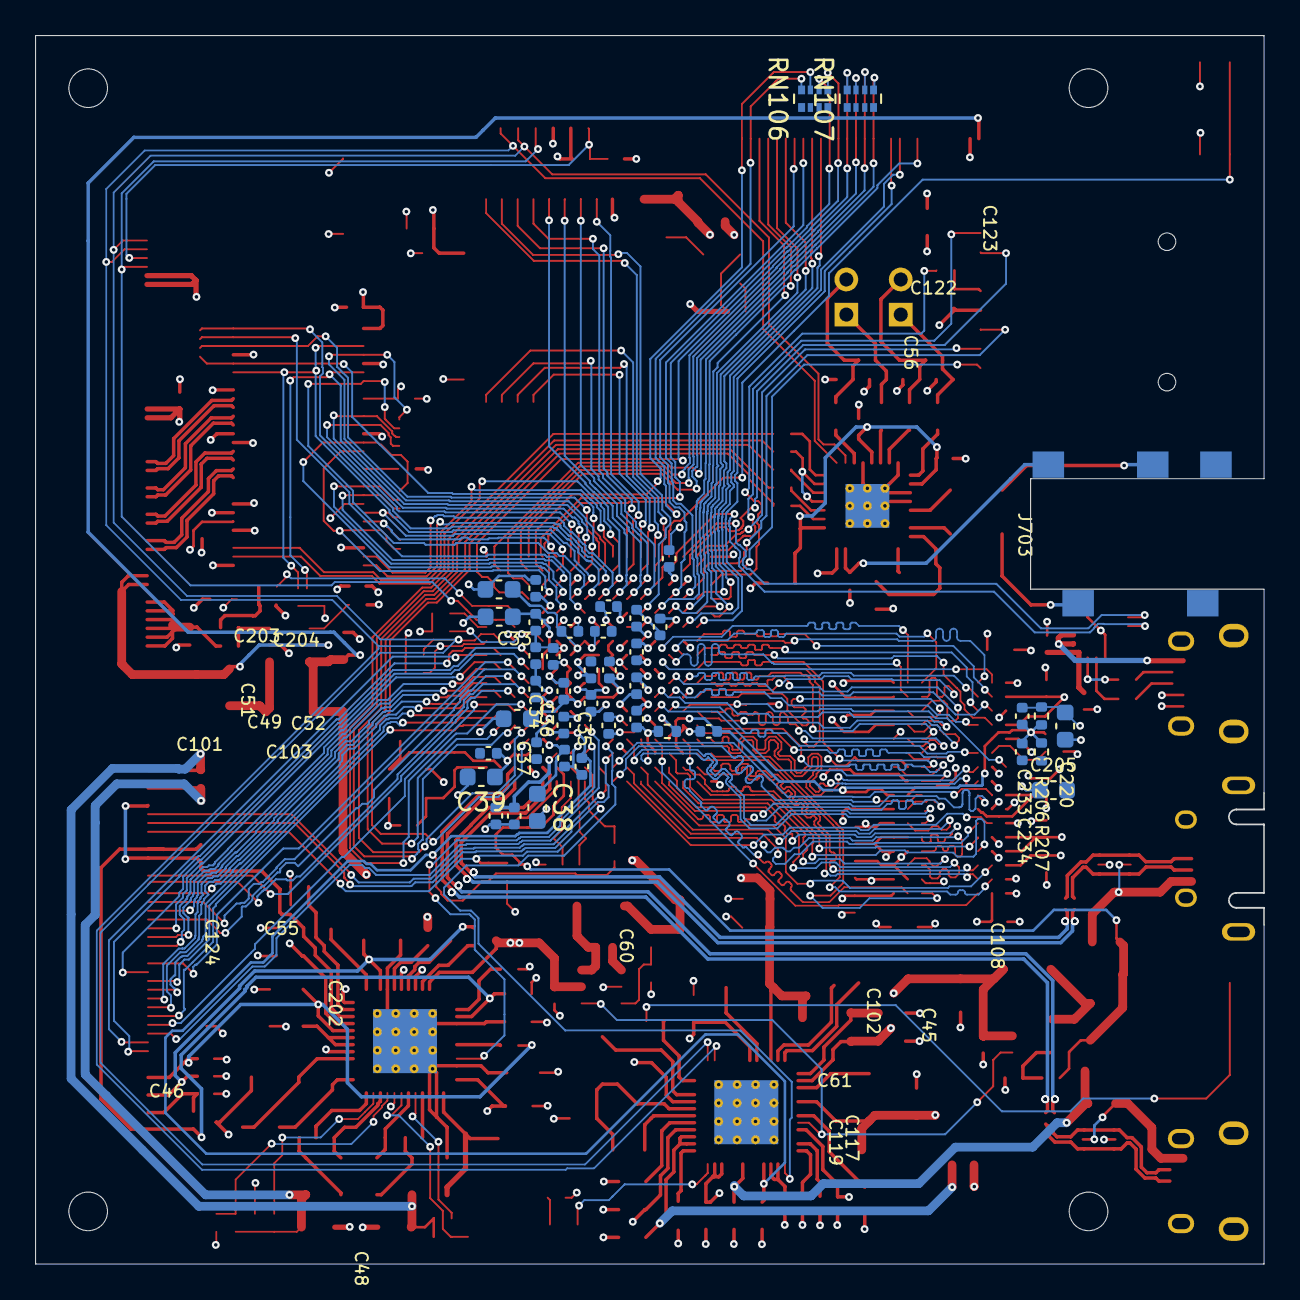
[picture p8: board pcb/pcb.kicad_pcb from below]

Board: 4 copper layers, 70.0 x 70.0 mm, 289 parts (42 on the bottom side), 275 nets.

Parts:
ANT901: PCB_WIFI_ANT; bt_antenna_1ant_2gnd
BT1: Conn_01x02; Molex_PicoBlade_53261-0271_1x02-1MP_P1.25mm_Horizontal
C1, C2, C3, C14, C15, C17, C18, C19, C20, C21, C23, C24, C26, C27, C32, C38, C39, C501, C519, C530, C905, C907: 10uF; C_0603_1608Metric
C4, C6, C119: 2.2uF; C_0402_1005Metric
C5, C34, C35, C36, C37, C45, C46, C48, C49, C51, C52, C55, C56, C101, C102, C103, C108, C114, C115, C117, C122, C123, C124, C201, C202, C203, C204, C207, C208, C210, C212, C213, C216, C217, C221, C222, C225, C226, C229, C230, C235, C236, C502, C504, C505, C507, C508, C510, C511, C513, C514, C524, C525, C526, C527: 220nF; C_0402_1005Metric
C7, C28, C30, C31, C33, C58, C220, C518, C529, C533, C534, C535, C537, C539, C710, C711: 4.7uF; C_0603_1608Metric
C8, C11, C12, C13, C29, C206, C233, C234, C403, C503, C512, C516, C540, C613, C615, C714, C715, C716, C717, C718, C904, C906: 100nF; C_0402_1005Metric
C9, C10, C515, C517, C521, C523, C532, C536, C538, C541: 4.7uF/25V; C_0805_2012Metric
C22, C25: 1nF; C_0402_1005Metric
C54, C60, C61, C205, C239, C240, C402, C528: 22uF; C_0603_1608Metric
C112, C113, C401: 18pF; C_0402_1005Metric
C116, C121: DNP/18pF; C_0402_1005Metric
C506: 1uF/35V; C_0603_1608Metric
C520: 10uF/6.3V; C_0603_1608Metric
C522, C531: 10nF; C_0402_1005Metric
C601, C602: 10uF/25V; C_0805_2012Metric
C705, C706, C707, C708, C709, C719, C720: 470nF; C_0402_1005Metric
C712, C713: 100uF; C_1206_3216Metric
C901, C902: DNP; C_0402_1005Metric
C903: 33pF/50V/5%; C_0402_1005Metric
D1: LED; D_0603_1608Metric
D2, D501, D502, D503, D504, D505, D506, D507: B0530WS; D_SOD-323
H1, H2, H3, H4: MountingHole; MountingHole_2.2mm_M2_DIN965
J300: Conn_01x30_MountingPin; TE_3-1734839-0_1x30-1MP_P0.5mm_Horizontal
J401: MICRO_SD(TFC-WPAPR-08); TFC-WPAPR-08
J501: 0.5mm; Hirose_FH12-40S-0.5SH_1x40-1MP_P0.50mm_Horizontal_Reversed
J502: Conn_01x30_MountingPin; Hirose_FH12-30S-0.5SH_1x30-1MP_P0.50mm_Horizontal_Reversed
J503: 1mm; Molex_200528-0060_1x06-1MP_P1.00mm_Horizontal_Reversed
J504: 0.5mm; Hirose_FH12-12S-0.5SH_1x12-1MP_P0.50mm_Horizontal_Reversed
J601: USB_AB_Micro; USB_Micro-AB_Molex_47590-0001
J602, J604: USB_B_Micro; USB_Micro-B_Amphenol_10103594-0001LF_Horizontal
J701, J702: Conn_01x02; PinHeader_1x02_P2.00mm_Vertical
J703: AudioJack3_SwitchT; PJ-327E
L1, L2, L3, L4, L5, L501: 4.7uH; L_1212
L502, L503: 2.2uH; L_1212
L601, L602: EXC14CE900U; L_CommonModeChoke_Panasonic_EXC14CE
L603, L604, L701, L702: 120R; L_0603_1608Metric
L703, L704, L705, L706: 15uH; L_0603_1608Metric
R2, R4: 1K; R_0402_1005Metric
R3: 200K; R_0402_1005Metric
R5: 200K/1%; R_0402_1005Metric
R6, R8: 27K/1%; R_0402_1005Metric
R7: 121K/1%; R_0402_1005Metric
R9: 0.03R; R_0805_2012Metric
R10: 1R; R_0603_1608Metric
R101, R104, R105, R107, R108, R110, R202, R203, R502, R503, R505, R508, R902: 10K; R_0402_1005Metric
R102, R103: DNP/10K; R_0402_1005Metric
R109: 1M; R_0402_1005Metric
R111: DNP/4.75M; R_0402_1005Metric
R201, R204: 240R 1%; R_0402_1005Metric
R206, R207: 1.5K/0.5%; R_0402_1005Metric
R401: 33; R_0402_1005Metric
R501, R901: 0R; R_0402_1005Metric
R504: 49.9K/1%; R_0402_1005Metric
R506: 3.3K; R_0402_1005Metric
R507: 1.8R; R_0402_1005Metric
R509, R516, R708: 100K; R_0402_1005Metric
R510: 976K/1%; R_0402_1005Metric
R511: 36K/1%; R_0402_1005Metric
R512: 43K; R_0402_1005Metric
R513, R514, R515, R517, R518: NC; R_0402_1005Metric
R519: 1M/1%; R_0402_1005Metric
R520: 52.3K/1%; R_0402_1005Metric
R606, R607: 22; R_0402_1005Metric
R703, R704, R705, R706, R707: 22R; R_0402_1005Metric
RN101, RN102, RN103, RN104, RN105, RN106, RN107: 10K; R_Array_Convex_4x0402
SW1, SW101: EVQPUJ02K; Panasonic_EVQPUJ_EVQPUA
TH1: 10K; R_0603_1608Metric
TH501: 10K; R_0402_1005Metric
U1: AXP209; QFN-48-1EP_6x6mm_P0.4mm_EP4.2x4.2mm_ThermalVias
U2: SY7208; SOT-23-6
U3: SY8120; TSOT-23-6
U100: MCIMX6Y7DVM09AB; BGA-289_17x17_14.0x14.0mm
U202: MT41K256M16HA; BGA-96_9.0x13.0mm_P0.8mm
U501: AP3031; SOT-23-6
U502: TPS65185; QFN-48-1EP_6x6mm_P0.4mm_EP4.2x4.2mm_ThermalVias
U503: DS90C385A/GM8285C; TSSOP-56_6.1x14mm_P0.5mm
U601, U605: USBLC6-2P6; SOT-666
U602: CP2102N-Axx-xQFN20; SiliconLabs_QFN-20-1EP_3x3mm_P0.5mm_EP1.8x1.8mm
U701: WM8960; QFN-32-1EP_5x5mm_P0.5mm_EP3.6x3.6mm_ThermalVias
U901: RTL8723BS; RL-SM02BD(RTL8723BS)
X901: 32.768kHz; Oscillator_SMD_Abracon_ASE-4Pin_3.2x2.5mm
Y101: 24MHz; Oscillator_SMD_Abracon_ASE-4Pin_3.2x2.5mm
Y102: 32.768kHz; Crystal_SMD_TXC_9HT11-2Pin_2.0x1.2mm_HandSoldering

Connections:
+1V5: C21.2, C22.2, C45.1, C48.1, C54.1, C58.1, L4.2, U1.10 (DCDC2), U100.H9 (VDD_SOC_IN), U100.H10 (VDD_SOC_IN), U100.J9 (VDD_SOC_IN), U100.J10 (VDD_SOC_IN), U100.K9 (VDD_SOC_IN), U100.K10 (VDD_SOC_IN)
+1V35: C24.2, C25.2, C201.1, C202.1, C203.1, C204.1, C205.1, C212.1, C213.1, C216.1, C217.1, C220.1, C221.1, C222.1, C225.1, C226.1, C229.1, C230.1, C233.1, C235.1, C236.1, C239.1, C240.1, L5.2, R206.1, U1.17 (DCDC3), U100.G6 (NVCC_DRAM), U100.H6 (NVCC_DRAM), U100.J6 (NVCC_DRAM), U100.K6 (NVCC_DRAM), U100.L6 (NVCC_DRAM), U100.M6 (NVCC_DRAM), U202.A1 (VDDQ), U202.A8 (VDDQ), U202.B2 (VDD), U202.C1 (VDDQ), U202.C9 (VDDQ), U202.D2 (VDDQ), U202.D9 (VDD), U202.E9 (VDDQ), U202.F1 (VDDQ), U202.G7 (VDD), U202.H2 (VDDQ), U202.H9 (VDDQ), U202.K2 (VDD), U202.K8 (VDD), U202.N1 (VDD), U202.N9 (VDD), U202.R1 (VDD), U202.R9 (VDD)
+3.3VA: C32.2, U1.11 (LDO4)
+3V3: C15.2, C17.2, C33.1, C34.1, C101.1, C102.1, C103.1, C108.1, C122.1, C123.1, C124.1, C402.1, C403.1, C512.1, C520.1, C524.1, C525.1, C526.1, C527.1, C528.1, C539.1, C705.1, C904.1, C905.1, C906.1, C907.1, J300.28, J401.4 (VDD), J502.2, J502.3, J503.2, J504.11, J504.12, L2.2, L701.2, L702.2, R7.2, R105.1, R107.1, R108.1, R110.1, R502.1, R508.1, R708.1, R902.1, RN101.5 (R4.2), RN101.6 (R3.2), RN101.7 (R2.2), RN101.8 (R1.2), U100.C4 (NVCC_SD1), U100.E7 (NVCC_NAND), U100.E13 (NVCC_LED), U100.F4 (NVCC_CSI), U100.F13 (NVCC_ENET), U100.H13 (NVCC_UART), U100.J13 (NVCC_GPIO), U100.L13 (VDDA_ADC_3P3), U100.M13 (ADC_VREFH), U100.N13 (VDD_HIGH_IN), U502.45 (VIN3P3), U503.1 (VCC), U503.9 (VCC), U503.26 (VCC), U503.34 (PLL_VCC), U503.44 (LVDS_VCC), U701.8 (DCVDD), U901.9 (VDD33), U901.22 (VDD_IO), X901.4 (Vdd)
+3V3_LCD: C510.1, C537.1, J501.5, J501.11, U502.46 (V3P3)
+5V: C14.2, C114.1, C115.1, C601.1, D2.1 (K), L603.1, R5.2, U100.T12 (USB_OTG1_VBUS), U100.U12 (USB_OTG2_VBUS)
+BATT: BT1.2, C3.1, C18.2, R9.2, U1.38 (BAT), U1.39 (BAT), U1.42 (BATSENSE)
+DRAM_VREF: C206.1, C208.1, C210.1, C233.2, C234.1, R206.2, R207.1, U100.P4 (DRAM_VREF), U202.H1 (VrefDQ), U202.M8 (VrefCA)
+RTC: C30.2, C35.1, R101.2, R103.2, U1.28 (LDO1), U100.P12 (VDD_SNVS_IN)
+VDD_HIGH_CAP: C207.1, U100.N6 (NVCC_DRAM_2P5)
/audio/MICBIAS: C715.1, U701.1 (MICBIAS)
/cpu/BOOTMODE1: R101.1, R102.2, U100.U10 (BOOT_MODE1)
/ddr/DRAM_ADDR0: U100.L5 (DRAM_ADDR0), U202.N3 (A0)
/ddr/DRAM_ADDR1: U100.H2 (DRAM_ADDR1), U202.P7 (A1)
/ddr/DRAM_ADDR2: U100.K1 (DRAM_ADDR2), U202.P3 (A2)
/ddr/DRAM_ADDR3: U100.M2 (DRAM_ADDR3), U202.N2 (A3)
/ddr/DRAM_ADDR4: U100.K4 (DRAM_ADDR4), U202.P8 (A4)
/ddr/DRAM_ADDR5: U100.L1 (DRAM_ADDR5), U202.P2 (A5)
/ddr/DRAM_ADDR6: U100.G2 (DRAM_ADDR6), U202.R8 (A6)
/ddr/DRAM_ADDR7: U100.H4 (DRAM_ADDR7), U202.R2 (A7)
/ddr/DRAM_ADDR8: U100.J4 (DRAM_ADDR8), U202.T8 (A8)
/ddr/DRAM_ADDR9: U100.L2 (DRAM_ADDR9), U202.R3 (A9)
/ddr/DRAM_ADDR10: U100.M4 (DRAM_ADDR10), U202.L7 (A10)
/ddr/DRAM_ADDR11: U100.K3 (DRAM_ADDR11), U202.R7 (A11)
/ddr/DRAM_ADDR12: U100.L4 (DRAM_ADDR12), U202.N7 (A12/~BC)
/ddr/DRAM_ADDR13: U100.H3 (DRAM_ADDR13), U202.T3 (A13)
/ddr/DRAM_ADDR14: U100.G1 (DRAM_ADDR14), U202.T7 (A14/NC)
/ddr/DRAM_BA0: U100.M1 (DRAM_SDBA0), U202.M2 (BA0)
/ddr/DRAM_BA1: U100.H1 (DRAM_SDBA1), U202.N8 (BA1)
/ddr/DRAM_BA2: U100.K2 (DRAM_SDBA2), U202.M3 (BA2)
/ddr/DRAM_CASB: U100.J2 (~DRAM_CAS), U202.K3 (~CAS)
/ddr/DRAM_CKE: R202.2, U100.M3 (DRAM_SDCKE0), U202.K9 (CKE)
/ddr/DRAM_CKN: U100.P2 (DRAM_SDCLK0_N), U202.K7 (~CK)
/ddr/DRAM_CKP: U100.P1 (DRAM_SDCLK0_P), U202.J7 (CK)
/ddr/DRAM_CSB: U100.N2 (~DRAM_CS0), U202.L2 (~CS)
/ddr/DRAM_DATA0: U100.T4 (DRAM_DATA0), U202.E3 (DQ0)
/ddr/DRAM_DATA1: U100.U6 (DRAM_DATA1), U202.F7 (DQ1)
/ddr/DRAM_DATA2: U100.T6 (DRAM_DATA2), U202.F2 (DQ2)
/ddr/DRAM_DATA3: U100.U7 (DRAM_DATA3), U202.F8 (DQ3)
/ddr/DRAM_DATA4: U100.U8 (DRAM_DATA4), U202.H3 (DQ4)
/ddr/DRAM_DATA5: U100.T8 (DRAM_DATA5), U202.H8 (DQ5)
/ddr/DRAM_DATA6: U100.T5 (DRAM_DATA6), U202.G2 (DQ6)
/ddr/DRAM_DATA7: U100.U4 (DRAM_DATA7), U202.H7 (DQ7)
/ddr/DRAM_DATA8: U100.U2 (DRAM_DATA8), U202.D7 (DQ8)
/ddr/DRAM_DATA9: U100.U3 (DRAM_DATA9), U202.C3 (DQ9)
/ddr/DRAM_DATA10: U100.U5 (DRAM_DATA10), U202.C8 (DQ10)
/ddr/DRAM_DATA11: U100.R4 (DRAM_DATA11), U202.C2 (DQ11)
/ddr/DRAM_DATA12: U100.P5 (DRAM_DATA12), U202.A7 (DQ12)
/ddr/DRAM_DATA13: U100.P3 (DRAM_DATA13), U202.A2 (DQ13)
/ddr/DRAM_DATA14: U100.R2 (DRAM_DATA14), U202.B8 (DQ14)
/ddr/DRAM_DATA15: U100.R1 (DRAM_DATA15), U202.A3 (DQ15)
/ddr/DRAM_DQM0: U100.T7 (DRAM_DQM0), U202.D3 (UDM)
/ddr/DRAM_DQM1: U100.T3 (DRAM_DQM1), U202.E7 (LDM)
/ddr/DRAM_ODT: U100.N1 (DRAM_ODT0), U202.K1 (ODT)
/ddr/DRAM_RASB: U100.M5 (~DRAM_RAS), U202.J3 (~RAS)
/ddr/DRAM_RST: R203.2, U100.G4 (DRAM_RESET), U202.T2 (~RESET)
/ddr/DRAM_WEB: U100.J1 (~DRAM_SDWE), U202.L3 (~WE)
/lcd/BORDER: C502.1, J501.40, R501.2
/lcd/EPD_TP_RST: C514.1, J503.1, J504.9, R502.2
/lcd/LEDA: C506.2, D501.1 (K), J502.21, J502.22, U501.5 (OVP)
/lcd/LEDK: J502.24, J502.25, J502.26, J502.27, J502.28, J502.29, R506.1, R507.1
/lcd/LVDS_CKN: J502.17, U503.40 (TxCLKOUT-)
/lcd/LVDS_CKP: J502.18, U503.39 (TxCLKOUT+)
/lcd/LVDS_D0N: J502.8, U503.48 (TxOUT0-)
/lcd/LVDS_D0P: J502.9, U503.47 (TxOUT0+)
/lcd/LVDS_D1N: J502.11, U503.46 (TxOUT1-)
/lcd/LVDS_D1P: J502.12, U503.45 (TxOUT1+)
/lcd/LVDS_D2N: J502.14, U503.42 (TxOUT2-)
/lcd/LVDS_D2P: J502.15, U503.41 (TxOUT2+)
/power/EXTEN: U1.20 (EXTEN), U2.4 (EN), U3.4 (RUN)
/power/NVCC_PLL: C37.1, C38.1, U100.P13 (NVCC_PLL)
/power/TS: TH1.1, U1.37 (TS)
/power/VDD_ARM_CAP: C51.1, C55.1, C60.1, U100.G9 (VDD_ARM_CAP), U100.G10 (VDD_ARM_CAP), U100.G11 (VDD_ARM_CAP), U100.H11 (VDD_ARM_CAP)
/power/VDD_HIGH_CAP: C39.1, C46.1, U100.R14 (VDD_HIGH_CAP), U100.R15 (VDD_HIGH_CAP)
/power/VDD_SNVS_CAP: C36.1, U100.N12 (VDD_SNVS_CAP)
/power/VDD_SOC_CAP: C49.1, C52.1, C56.1, C61.1, U100.G8 (VDD_SOC_CAP), U100.H8 (VDD_SOC_CAP), U100.J8 (VDD_SOC_CAP), U100.J11 (VDD_SOC_CAP), U100.K8 (VDD_SOC_CAP), U100.K11 (VDD_SOC_CAP), U100.L8 (VDD_SOC_CAP), U100.L9 (VDD_SOC_CAP), U100.L10 (VDD_SOC_CAP), U100.L11 (VDD_SOC_CAP)
/power/VINT: C4.1, U1.26 (VINT), U1.27 (LDO1SET)
/usb/DEVICE_DN: J602.2 (D-), L601.4, U605.1 (I/O1), U605.6 (I/O1)
/usb/DEVICE_DP: J602.3 (D+), L601.3, U605.3 (I/O2), U605.4 (I/O2)
/usb/HOST_DN: J601.2 (D-), L602.3, U601.1 (I/O1), U601.6 (I/O1)
/usb/HOST_DP: J601.3 (D+), L602.4, U601.3 (I/O2), U601.4 (I/O2)
CSI_D0: J300.2, RN106.7 (R2.2), U100.B13 (LCD_DATA17)
CSI_D1: J300.3, RN106.8 (R1.2), U100.C13 (LCD_DATA16)
CSI_D2: J300.4, U100.E4 (CSI_DATA0)
CSI_D3: J300.5, U100.E3 (CSI_DATA1)
CSI_D4: J300.6, U100.E2 (CSI_DATA2)
CSI_D5: J300.7, U100.E1 (CSI_DATA3)
CSI_D6: J300.8, U100.D4 (CSI_DATA4)
CSI_D7: J300.9, U100.D3 (CSI_DATA5)
CSI_D8: J300.10, U100.D2 (CSI_DATA6)
CSI_D9: J300.11, U100.D1 (CSI_DATA7)
CSI_D10: J300.12, RN106.6 (R3.2), U100.A13 (LCD_DATA18)
CSI_D11: J300.13, RN106.5 (R4.2), U100.D14 (LCD_DATA19)
CSI_D12: J300.14, RN107.8 (R1.2), U100.C14 (LCD_DATA20)
CSI_D13: J300.15, RN107.7 (R2.2), U100.B14 (LCD_DATA21)
CSI_D14: J300.16, RN107.6 (R3.2), U100.A14 (LCD_DATA22)
CSI_D15: J300.17, RN107.5 (R4.2), U100.B16 (LCD_DATA23)
CSI_HSYNC: J300.20, U100.F3 (CSI_HSYNC)
CSI_PIXCLK: J300.22, U100.E5 (CSI_PIXCLK)
CSI_VSYNC: J300.19, U100.F2 (CSI_VSYNC)
EPDC_D0: J501.14, U100.L14 (GPIO1_IO2)
EPDC_D1: J501.15, U100.L17 (GPIO1_IO3)
EPDC_D2: J501.16, U100.K14 (UART1_TX_DATA)
EPDC_D3: J501.17, U100.K16 (UART1_RX_DATA)
EPDC_D4: J501.18, U100.K15 (~UART1_CTS)
EPDC_D5: J501.19, U100.J14 (~UART1_RTS)
EPDC_D6: J501.20, U100.J17 (UART2_TX_DATA)
EPDC_D7: J501.21, U100.J16 (UART2_RX_DATA)
EPDC_D8: J501.23, U100.J15 (~UART1_CTS)
EPDC_D9: J501.24, U100.H14 (~UART2_RTS)
EPDC_D10: J501.25, U100.M16 (GPIO1_IO4)
EPDC_D11: J501.26, U100.M17 (GPIO1_IO5)
EPDC_D12: J501.27, U100.K17 (GPIO1_IO6)
EPDC_D13: J501.28, U100.L16 (GPIO1_IO7)
EPDC_D14: J501.29, U100.N17 (GPIO1_IO8)
EPDC_D15: J501.30, U100.M15 (GPIO1_IO9)
EPDC_GDCLK: J501.7, U100.R8 (ONOFF)
EPDC_GDOE: J501.6, U100.T9 (SNVS_PMIC_ON_REQ)
EPDC_GDSP: J501.8, R103.1, R104.2, U100.T10 (BOOT_MODE0)
EPDC_SDCE0: J501.31, U100.N10 (SNVS_TAMPER7)
EPDC_SDCLK: J501.13, U100.L15 (GPIO1_IO1)
EPDC_SDLE: J501.32, U100.H17 (UART3_TX_DATA)
EPDC_SDOE: J501.33, U100.H16 (UART3_RX_DATA)
EPD_PWR_EN: U100.R10 (SNVS_TAMPER0), U502.21 (PWRUP)
EPD_TP_INT: J503.4, J504.10, U100.F15 (ENET1_TX_EN)
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

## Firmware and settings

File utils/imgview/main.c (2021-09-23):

//
// NekoInk Image Viewer
// Copyright 2021 Wenting Zhang
//
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
// File : main.c
// Brief: Main entry point of the application
//
#include <stdio.h>
#include <stdlib.h>
#include <stdbool.h>
#include <stdint.h>
#include <time.h>
#include "config.h"
#include "disp.h"

#if defined(BUILD_PC_SIM)
#include <SDL.h>
#endif

#define PROFILE(x) { \
    clock_t t = clock();\
    x;\
    t = clock() - t;\
    printf("%.2f ms\n", (double)t / CLOCKS_PER_SEC * 1000);\
}

void dump_hex(uint8_t *buf, int count) {
    for (int i = 0; i < count / 16; i++) {
        for (int j = 0; j < 16; j++) {
            printf("%02x ", *buf++);
        }
        printf("\n");
    }
}

int main(int argc, char *argv[]) {
    if (argc < 2) {
        fprintf(stderr, "Usage: imgview <path_to_image>\n");
        return 1;
    }

#ifdef ENABLE_COLOR
    Canvas *target = disp_create(DISP_WIDTH, DISP_HEIGHT, PIXFMT_RGB888);
#else
    Canvas *target = disp_create(DISP_WIDTH, DISP_HEIGHT, PIXFMT_Y8);
#endif
    Rect zero_rect = {0};

    disp_init();

    Canvas *image;
    
    printf("Loading image: ");
    PROFILE(image = disp_load_image(argv[1]));

    if (image->pixelFormat != target->pixelFormat) {
        Canvas *image_new = disp_create(image->width, image->height, target->pixelFormat);

        printf("Converting image: ");
        PROFILE(disp_conv(image_new, image));
        disp_free(image);
        image = image_new;
    }

    printf("Scaling image: ");
    PROFILE(disp_scale_image_fit(image, target));

    printf("Filtering image: ");
    PROFILE(disp_filtering_image(target, zero_rect, zero_rect));

    printf("Present image: ");
    PROFILE(disp_present(zero_rect, WVMD_GC16, true, true));

#if defined(BUILD_PC_SIM)
    SDL_Event event;
    float time_delta = 0.0f;
    int last_ticks = SDL_GetTicks();
    bool running = true;

    while (running) {
        int cur_ticks = SDL_GetTicks();
        time_delta -= cur_ticks - last_ticks; // Actual ticks passed since last iteration
        time_delta += 1000.0f / (float)TARGET_FPS; // Time allocated for this iteration
        last_ticks = cur_ticks;

        // Process SDL events
        while (SDL_PollEvent(&event)) {
            if (event.type == SDL_QUIT) {
                running = false;
            }
            else {
                // handle events
            }
        }

        // Wait for next frame
        int time_to_wait = time_delta - (SDL_GetTicks() - last_ticks);
        if (time_to_wait > 0)
            SDL_Delay(time_to_wait);
    }
#endif

    disp_deinit();

    return 0;
}

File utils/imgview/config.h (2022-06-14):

#pragma once

// Choose build target
// PC simulator uses SDL for input and output
// Target uses fbdev and evdev directly
// Should be defined in Makefile
//#define BUILD_PC_SIM
//#define BUILD_NEKOINK

// Target resolution
#if defined(BUILD_PC_SIM)
#define TITLE "IMGVIEW"
#define TARGET_FPS (30)
#define DISP_WIDTH (1448)
#define DISP_HEIGHT (1072)
#elif defined(BUILD_NEKOINK)
#define DISP_WIDTH (2232)
#define DISP_HEIGHT (1680)
#endif

#define DISP_GAMMA (2.2f)

#define ENABLE_COLOR

#ifdef ENABLE_COLOR
// Options only applies if COLOR is enabled
//#define ENABLE_LPF // Enable LPF to avoid jagged edges
//#define ENABLE_BRIGHTEN // Copy component to neighbor pixels, only valid on SIM
#endif

#define DEPTH_1BPP // monochrome
//#define DEPTH_2BPP // 4 grey / 64 color
//#define DEPTH_4BPP // 16 grey / 4096 color
//#define DEPTH_8BPP

// Define either one of them to enable dithering
#define DITHERING_ERROR_DIFFUSION
//#define DITHERING_ORDERED
//#define DITHERING_BLUE_NOISE

// Dithering options
#ifdef ENABLE_COLOR
    #define DITHERING_ERRBUF_LINES (4)
#else
    #define DITHERING_ERRBUF_LINES (2)
#endif
#define DITHERING_GAMMA_AWARE

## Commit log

2021-09-03 pcb: r0p1 wip
    [audio.kicad_sch, caster.kicad_sch, cpu.kicad_sch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]
2021-09-05 pcb: finish routing r0p1
    [cpu.kicad_sch, ddr.kicad_sch, pcb.kicad_sch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]
2021-09-06 pcb: revise r0p1 design, ready for production
    [pcb.kicad_sch, power.kicad_sch]
2021-09-10 utils: waveform assembler wip
2021-09-12 utils: initial waveform assembler for imx6/7 epdc
2021-09-12 waveform: add raw waveform for gdew101
    [test_M0_T0.csv, test_M1_T0.csv, test_M2_T0.csv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]
2021-09-18 - Preparing for actual hardware target - Use LUT for gamma correction
    [main.c]
2021-09-18 utils: add spreadsheet for timing calculation
    [epd_timing.ods]
2021-09-19 utils: fix memory issues in waveform asm
    [main.c]
2021-09-21 utils: new fw dump tool; support for v2 epdc format; new iwf allows different table length for different temperatures
2021-10-03 pcb: getting ready for r0.2 production
    [audio.kicad_sch, caster.kicad_sch, cpu.kicad_sch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]
2021-10-16 pcb: move mb to its own directory
    [cpu.kicad_sch, ddr.kicad_sch, expansion.kicad_sch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]
2021-10-18 pcb: switch to max17135, length tuning for QSPI and SD
    [cpu.kicad_sch, expansion.kicad_sch, lcd.kicad_sch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]
2021-11-14 pcb: mainboard r0.2 freeze
2022-03-05 - Update to KiCad 6.0 - Fix MT41K256M16 symbol missing pin in library
    [cpu.kicad_sch, ddr.kicad_sch, expansion.kicad_sch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]
2022-05-28 pcb: adapter for 39p/50p screens
    [adapter.kicad_pcb, adapter.kicad_sch]
2022-05-29 pcb: adapter for 34p screens
    [adapter.kicad_pcb, adapter.kicad_sch]
2022-06-14 util: fix dithering for color panel; implement blue noise and ordered dithering
    [config.h]
2023-07-02 Add adapter board for 35pin connector
    [adapter.kicad_pcb, adapter.kicad_sch]
2023-12-27 Revert "Triton 2 color support"
    This reverts commit 02d3daa51657f19f5df007baddab4ebbc355173f.
    [config.h]
2024-01-14 Shelved Gen2 board design
    [connector.kicad_sch, cpu.kicad_sch, ddr.kicad_sch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]

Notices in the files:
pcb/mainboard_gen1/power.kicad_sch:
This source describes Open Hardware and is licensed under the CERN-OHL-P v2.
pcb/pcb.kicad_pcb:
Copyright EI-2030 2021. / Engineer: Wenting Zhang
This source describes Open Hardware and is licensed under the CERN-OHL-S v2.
